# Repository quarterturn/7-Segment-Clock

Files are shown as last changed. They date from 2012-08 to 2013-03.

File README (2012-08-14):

A 7-segment clock based on the ATMEGA 328p, MAX7219 led driver, a DS1307 RTC and some old HP calculator common-cathode bubble lens displays.

Clock features:
- displays time: hh.mm.ss A.
  if 12-hour, shows A or P
  if alarm set, shows . in the A/P position
- displays date: mm.dd.yy D
  shows the day of week 1-7 at D
- when the date display is selected, the time scrolls over while still keeping time to reveal the date, pauses, and then scrolls back
- during set mode, the selected value blinks
- allows for start/stop schedule for DST, as well as disabling DST conversion
- DST conversion also works during time set; if in DST, the time is converted back to STD for the RTC
- RTC stores time in STD local time
- alarm function allows none, weekends, weekdays and all days schedule

Includes free Nyan Cat alarm tune. Tunes are made with the miditones utility and played via the Playtune library.

Note that though there are three timers on the ATMEGA 328p we use timer0 for millis() so we limit Playtune polyphony to two notes.

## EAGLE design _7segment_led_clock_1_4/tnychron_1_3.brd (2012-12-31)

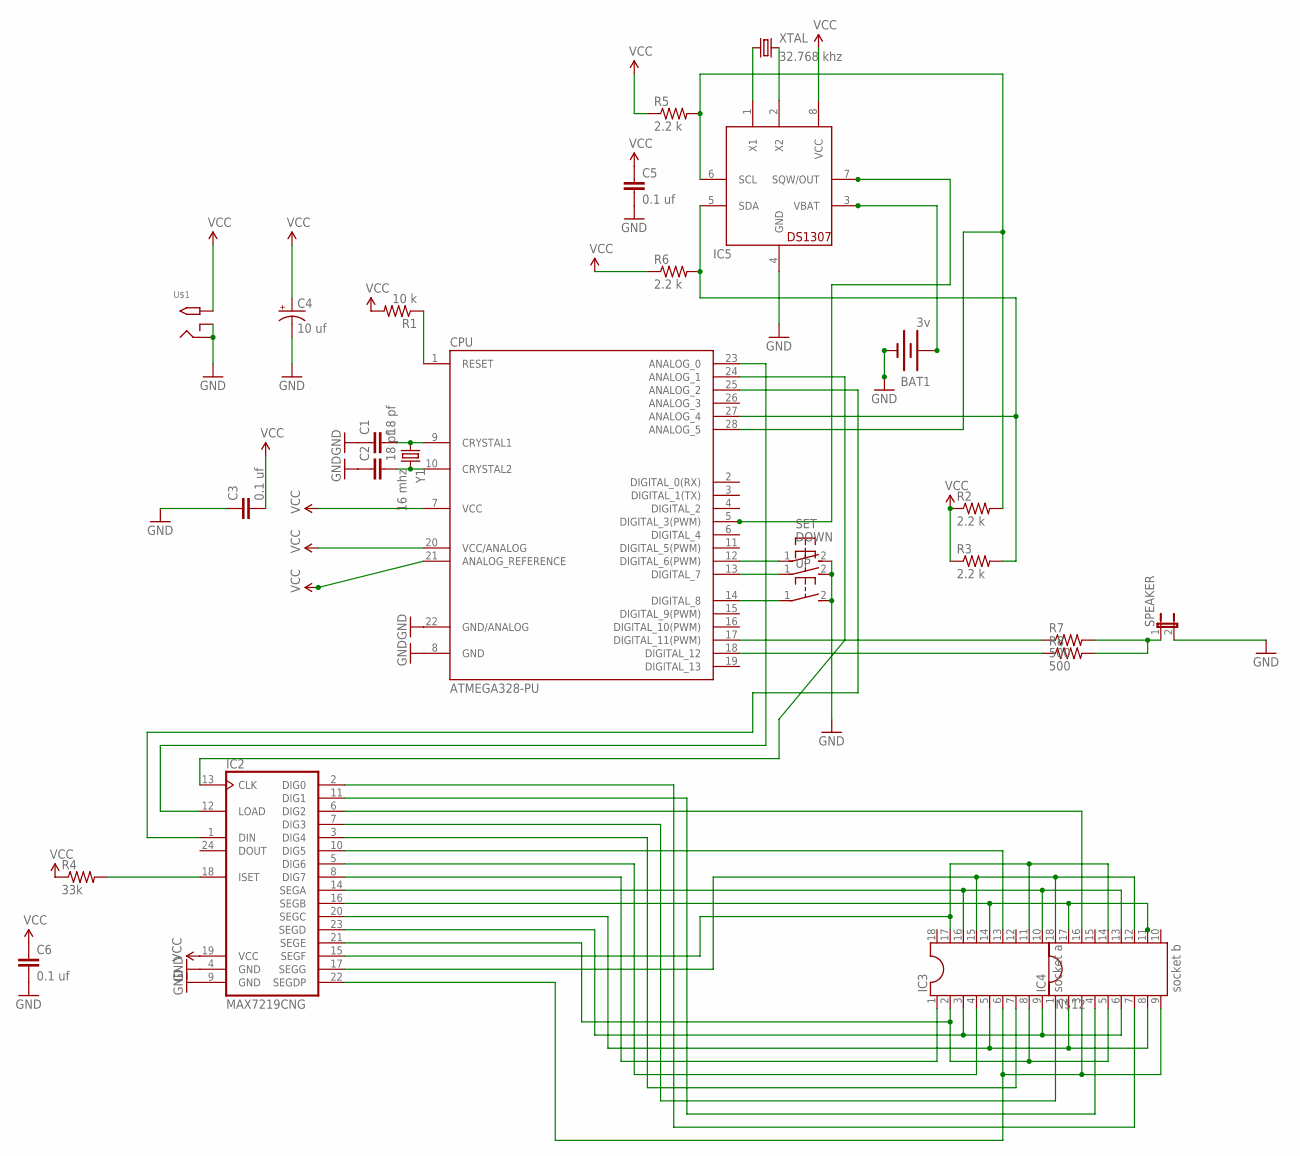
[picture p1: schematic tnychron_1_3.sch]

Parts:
BAT1: 3v; BATTCON_12MM_PTH
C1, C2: 18 pf; CAP-PTH-SMALL2
C3, C5, C6: 0.1 uf; CAP-PTH-SMALL2
C4: 10 uf; CPOL-RADIAL-10UF-25V
CPU: ATMEGA328-PU; DIL28-3
DOWN: 31-XX; B3F-31XX
IC2: MAX7219CNG; DIL24-3
IC3: socket a; DIL18
IC4: socket b; DIL18
IC5: DS1307; DIL08
R1: 10 k; AXIAL-0.4
R2, R3, R5, R6: 2.2 k; AXIAL-0.4
R4: 33k; AXIAL-0.4
R7, R8: 500; AXIAL-0.3
SET: 31-XX; B3F-31XX
SPEAKER: JUMPER-2PTH; 1X02
U$1: 2.1MMJACKTHM; PJ-102A
UP: 31-XX; B3F-31XX
XTAL: 32.768 khz; TC26H
Y1: 16 mhz; HC49US

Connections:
GND: BAT1.GND (-), C1.1, C2.1, C3.1, C4.2 (-), C5.2, C6.2, CPU.8 (GND), CPU.22 (GND/ANALOG), DOWN.2 (S), IC2.4 (GND), IC2.9 (GND), IC5.4 (GND), SET.2 (S), SPEAKER.2, U$1.RING, U$1.RING_SW, UP.2 (S)
unnamed: CPU.18 (DIGITAL_12), R8.P$1 (1)
unnamed: CPU.1 (RESET), R1.P$1 (1)
unnamed: C1.2, CPU.9 (CRYSTAL1), Y1.1
unnamed: C2.2, CPU.10 (CRYSTAL2), Y1.2
unnamed: IC2.2 (DIG0), IC4.7
unnamed: IC2.11 (DIG1), IC4.4
unnamed: CPU.28 (ANALOG_5), IC5.6 (SCL), R2.P$2 (2), R5.P$2 (2)
unnamed: CPU.27 (ANALOG_4), IC5.5 (SDA), R3.P$2 (2), R6.P$2 (2)
unnamed: CPU.5 (DIGITAL_3(PWM)), IC5.7 (SQW/OUT)
unnamed: CPU.17 (DIGITAL_11(PWM)), R7.P$1 (1)
unnamed: IC2.6 (DIG2), IC4.16
unnamed: IC2.7 (DIG3), IC4.1
unnamed: IC2.18 (ISET), R4.P$2 (2)
unnamed: IC2.3 (DIG4), IC3.7
unnamed: CPU.23 (ANALOG_0), IC2.12 (LOAD)
unnamed: CPU.24 (ANALOG_1), IC2.13 (CLK)
unnamed: CPU.25 (ANALOG_2), IC2.1 (DIN)
unnamed: IC2.10 (DIG5), IC3.13
unnamed: IC5.1 (X1), XTAL.1
unnamed: IC2.5 (DIG6), IC3.4
unnamed: IC2.8 (DIG7), IC3.1
unnamed: BAT1.VCC@1 (+), IC5.3 (VBAT)
unnamed: IC2.14 (SEGA), IC3.10, IC3.16, IC4.13
unnamed: IC2.16 (SEGB), IC3.14, IC4.11, IC4.17
unnamed: IC2.20 (SEGC), IC3.5, IC4.2, IC4.8
unnamed: IC2.23 (SEGD), IC3.3, IC3.9, IC4.6
unnamed: IC2.21 (SEGE), IC3.2, IC3.8, IC4.5
unnamed: CPU.12 (DIGITAL_6(PWM)), SET.1
unnamed: CPU.13 (DIGITAL_7), DOWN.1
unnamed: IC2.15 (SEGF), IC3.11, IC3.17, IC4.14
unnamed: IC2.17 (SEGG), IC3.15, IC4.12, IC4.18
unnamed: IC2.22 (SEGDP), IC3.6, IC4.3, IC4.9
unnamed: CPU.14 (DIGITAL_8), UP.1
unnamed: R7.P$2 (2), R8.P$2 (2), SPEAKER.1
unnamed: IC5.2 (X2), XTAL.2
VCC: C3.2, C4.1 (+), C5.1, C6.1, CPU.7 (VCC), CPU.20 (VCC/ANALOG), CPU.21 (ANALOG_REFERENCE), IC2.19 (VCC), IC5.8 (VCC), R1.P$2 (2), R2.P$1 (1), R3.P$1 (1), R4.P$1 (1), R5.P$1 (1), R6.P$1 (1), U$1.TIP

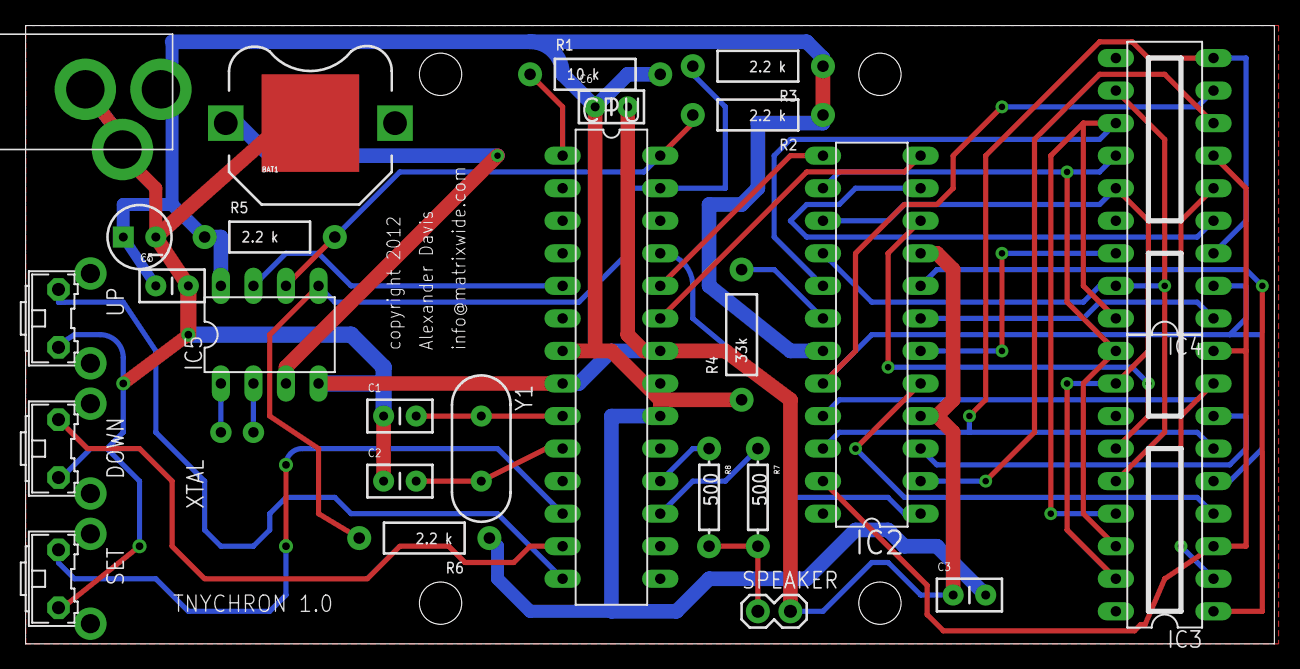
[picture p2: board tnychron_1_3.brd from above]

Board: 2 copper layers, 97.5 x 48.2 mm, 31 parts (1 on the bottom side), 37 nets.

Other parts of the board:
U$4, U$5, U$6, U$7: STAND-OFF

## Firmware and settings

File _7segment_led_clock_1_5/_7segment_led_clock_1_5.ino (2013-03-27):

/* teeny led clock
 
 Keeps time using a DS1307 RTC chip.
 
 The clock is controlled via a three button interface.
 
 The display is 3 HP 5082-7433 LED bubble displays driven by a MAX7219
 
 Version: 1.5
 Author: Alexander Davis
 Hardwarwe: ATMEGA328
 
 Uses the TimeLord library http://www.swfltek.com/arduino/timelord.html for DST calculation.
 
 Digital pins used:
 3 INT/SQW from DS1307 (active-low, set internal pull-up)
 10, 11, 12 for the MAX7219
 6, 7, 8 for buttons (active-low; set internal pull-ups to avoid external pull-down)
 
 Analog pins used:
 5, 4 i2c for DS1307
 */
 
 // Compatible with Ardunio 1.0

// for reading flash memory
#include <avr/pgmspace.h>
// for using atmega eeprom
#include <EEPROM.h>
// debounced button library
#include <Bounce.h>
// for 7 segment MAX7219 control
#include "LedControl.h"
// for using i2c interface
#include <Wire.h>
// for playing music
#include <Playtune.h>

// for time calculations
#include <TimeLord.h>

// global constants
#define SQW_PIN 3
#define SERIAL_BAUD 9600

// menus
#define M_INTRO 0
#define M_SET_TIME 1
#define M_SET_DATE 2
#define M_SET_AL 3
#define M_SET_24_HR 4
#define M_SET_DST 5
#define M_SET_DEFAULTS 6
#define M_SET_DONE 7
#define NUM_MENUS 7

#define SET_DEFAULTS 3
// to help remember time setting positions
#define HOURS_SET 0
#define MINUTES_SET 1
#define SECONDS_SET 2
#define PM_SET 3
// to help remember date setting positions
#define MONTHS_SET 0
#define DAYS_SET 1
#define YEARS_SET 2
#define DOW_SET 3
// to help remember alarm setting positions
#define AL_HOURS_SET 0
#define AL_MINUTES_SET 1
#define AL_DAY_SET 2
// to help remember for dst settings
#define DST_START_MON 0
#define DST_START_WEEK 1
#define DST_END_MON 2
#define DST_END_WEEK 3
#define DST_ENABLE 4
// to help remember the 12/24 hour settings
#define MODE_12_24_HOUR 0
// EEPROM memory locations for stored value
#define EE_DST_MON_START 0
#define EE_DST_WEEK_START 1
#define EE_DST_MON_END 2
#define EE_DST_WEEK_END 3
#define EE_TIME_MODE 4
#define EE_DST_ENABLE 5
#define EE_AL_HR 9
#define EE_AL_MIN 10
#define EE_AL_MODE 11

// how long to display the date
// 5 seconds
#define DATE_DELAY 5000

// how long to wait between scroll steps
// 250 mS
#define SCROLL_DELAY 200

// left side window rightmost scroll limit in display buffer
#define RIGHT_LIMIT 10
// left side window leftmost scroll limit in display buffer
#define LEFT_LIMIT 0

//i2c address of ds3231
#define DS1307_I2C_ADDRESS 0x68

// button setup - bounce objects
// 10 msec debounce interval
Bounce setButton = Bounce(6, 25);
Bounce decButton = Bounce(7, 25);
Bounce incButton = Bounce(8, 25);

// daylight savings time start and stop
byte dstMonStart;
byte dstDowStart = 1;
byte dstWeekStart;
byte dstMonEnd;
byte dstDowEnd = 1;
byte dstWeekEnd;
byte dstChangeHr = 2;
byte dstEnable = 1;
// 12 hour mode flag
byte is12Hour;

// day of week
byte day;
  
// array offsets
// 0 second
// 1 minute
// 2 hour
// 3 day
// 4 month
// 5 year

// dst time
byte theTime[6];

// alarm hour
byte alarmHr;
// alarm minute
byte alarmMin;
// alarm mode
// 0 - off
// 2 - weekends
// 5 - weekdays
// 7 - every day
byte alarmMode;

// flag if alarm should play
byte alarmPlay = 0;

// create a TimeLord object
TimeLord myLord;

/*
 LedControl pins
 pin 12 is connected to the DataIn 
 pin 11 is connected to the CLK 
 pin 10 is connected to LOAD 
 We have only a single MAX72XX.
 */
LedControl lc=LedControl(16,15,14,1);

// flag if time is ready per pin 3 interrupt
volatile byte displayNow = 0;

// track if date should be shown
byte showDate = 0;

// 16 character display buffer
char displayBuffer[18];

// there are 8 digits to the LED display
// therefore we use an 8 character window from the display buffer
// to display data
// left side of display window
byte dwL = 0;
// right side of display window
byte dwR = 7;

// delay for holding on the date display
int dateDelay = DATE_DELAY;

// for tracking time in delay loops
unsigned long previousMillis;

// string to be stored in flash at compile time
prog_char menu0[] PROGMEM = "TNYCHRON";
prog_char menu1[] PROGMEM = "SET TIME";
prog_char menu2[] PROGMEM = "SET DATE";
prog_char menu3[] PROGMEM = "SET AL  ";
prog_char menu4[] PROGMEM = "SET 24HR";
prog_char menu5[] PROGMEM = "SET DST ";
prog_char menu6[] PROGMEM = "SET DFLT";
prog_char menu7[] PROGMEM = "DONE    ";

// Playtune bytestream for file "nyancat1.mid" created by MIDITONES V1.4 on Sat Aug 11 09:57:09 2012
byte PROGMEM score [] = {
0x90,0x4E, 0x91,0x28, // 
0,214, 0x80, 0x81, 0x90,0x50, 0x91,0x34, 0,214, 0x80, 0x81, 0x90,0x4B, 0x91,0x2A, 0,107, 
0x80, 0x90,0x4B, 0,107, 0x81, 0x91,0x36, 0,107, 0x80, 0x90,0x47, 0,107, 0x81, 0x80, 0x91,0x27, 0x90,0x4A, 
0,107, 0x80, 0x90,0x49, 0,107, 0x81, 0x80, 0x91,0x33, 0x90,0x47, 0,214, 0x81, 0x80, 0x91,0x2C, 0x90,0x47, 
0,214, 0x81, 0x80, 0x91,0x38, 0x90,0x49, 0,214, 0x81, 0x80, 0x91,0x25, 0x90,0x4A, 0,214, 0x81, 0x80, 0x91,0x31, 
0x90,0x4A, 0,107, 0x80, 0x90,0x49, 0,107, 0x81, 0x80, 0x91,0x2A, 0x90,0x47, 0,107, 0x80, 0x90,0x49, 0,107, 
0x81, 0x80, 0x91,0x36, 0x90,0x4B, 0,107, 0x80, 0x90,0x4E, 0,107, 0x81, 0x80, 0x91,0x23, 0x90,0x50, 0,107, 
0x80, 0x90,0x4B, 0,107, 0x81, 0x80, 0x91,0x2F, 0x90,0x4E, 0,107, 0x80, 0x90,0x49, 0,107, 0x81, 0x80, 0x91,0x23, 
0x90,0x4B, 0,107, 0x80, 0x90,0x47, 0,107, 0x81, 0x80, 0x91,0x2F, 0x90,0x49, 0,107, 0x80, 0x90,0x47, 0,107, 
0x81, 0x80, 0x91,0x28, 0x90,0x4B, 0,214, 0x81, 0x80, 0x91,0x34, 0x90,0x4E, 0,214, 0x81, 0x80, 0x91,0x2A, 0x90,0x50, 
0,107, 0x80, 0x90,0x4B, 0,107, 0x81, 0x80, 0x91,0x36, 0x90,0x4E, 0,107, 0x80, 0x90,0x49, 0,107, 0x81, 
0x80, 0x91,0x27, 0x90,0x4B, 0,107, 0x80, 0x90,0x47, 0,107, 0x81, 0x80, 0x91,0x33, 0x90,0x49, 0,107, 0x80, 
0x90,0x4B, 0,107, 0x81, 0x80, 0x91,0x2C, 0x90,0x4A, 0,107, 0x80, 0x90,0x49, 0,107, 0x81, 0x80, 0x91,0x38, 
0x90,0x47, 0,107, 0x80, 0x90,0x49, 0,107, 0x81, 0x80, 0x91,0x25, 0x90,0x4A, 0,214, 0x81, 0x80, 0x91,0x31, 
0x90,0x47, 0,107, 0x80, 0x90,0x49, 0,107, 0x81, 0x80, 0x91,0x2A, 0x90,0x4A, 0,107, 0x80, 0x90,0x4E, 0,107, 
0x81, 0x80, 0x91,0x36, 0x90,0x49, 0,107, 0x80, 0x90,0x4B, 0,107, 0x81, 0x80, 0x91,0x23, 0x90,0x49, 0,107, 
0x80, 0x90,0x47, 0,107, 0x81, 0x80, 0x91,0x2F, 0x90,0x49, 0,214, 0x81, 0x80, 0x91,0x23, 0x90,0x47, 0,214, 
0x81, 0x80, 0x91,0x2F, 0x90,0x49, 0,214, 0x81, 0x80, 0x91,0x28, 0x90,0x4E, 0,214, 0x81, 0x80, 0x91,0x34, 0x90,0x50, 
0,214, 0x81, 0x80, 0x91,0x2A, 0x90,0x4B, 0,107, 0x80, 0x90,0x4B, 0,107, 0x81, 0x91,0x36, 0,107, 0x80, 
0x90,0x47, 0,107, 0x81, 0x80, 0x91,0x27, 0x90,0x4A, 0,107, 0x80, 0x90,0x49, 0,107, 0x81, 0x80, 0x91,0x33, 
0x90,0x47, 0,214, 0x81, 0x80, 0x91,0x2C, 0x90,0x47, 0,214, 0x81, 0x80, 0x91,0x38, 0x90,0x49, 0,214, 0x81, 
0x80, 0x91,0x25, 0x90,0x4A, 0,214, 0x81, 0x80, 0x91,0x31, 0x90,0x4A, 0,107, 0x80, 0x90,0x49, 0,107, 0x81, 
0x80, 0x91,0x2A, 0x90,0x47, 0,107, 0x80, 0x90,0x49, 0,107, 0x81, 0x80, 0x91,0x36, 0x90,0x4B, 0,107, 0x80, 
0x90,0x4E, 0,107, 0x81, 0x80, 0x91,0x23, 0x90,0x50, 0,107, 0x80, 0x90,0x4B, 0,107, 0x81, 0x80, 0x91,0x2F, 
0x90,0x4E, 0,107, 0x80, 0x90,0x49, 0,107, 0x81, 0x80, 0x91,0x23, 0x90,0x4B, 0,107, 0x80, 0x90,0x47, 0,107, 
0x81, 0x80, 0x91,0x2F, 0x90,0x49, 0,107, 0x80, 0x90,0x47, 0,107, 0x81, 0x80, 0x91,0x28, 0x90,0x4B, 0,214, 
0x81, 0x80, 0x91,0x34, 0x90,0x4E, 0,214, 0x81, 0x80, 0x91,0x2A, 0x90,0x50, 0,107, 0x80, 0x90,0x4B, 0,107, 
0x81, 0x80, 0x91,0x36, 0x90,0x4E, 0,107, 0x80, 0x90,0x49, 0,107, 0x81, 0x80, 0x91,0x27, 0x90,0x4B, 0,107, 
0x80, 0x90,0x47, 0,107, 0x81, 0x80, 0x91,0x33, 0x90,0x49, 0,107, 0x80, 0x90,0x4B, 0,107, 0x81, 0x80, 0x91,0x2C, 
0x90,0x4A, 0,107, 0x80, 0x90,0x49, 0,107, 0x81, 0x80, 0x91,0x38, 0x90,0x47, 0,107, 0x80, 0x90,0x49, 0,107, 
0x81, 0x80, 0x91,0x25, 0x90,0x4A, 0,214, 0x81, 0x80, 0x91,0x31, 0x90,0x47, 0,107, 0x80, 0x90,0x49, 0,107, 
0x81, 0x80, 0x91,0x2A, 0x90,0x4A, 0,107, 0x80, 0x90,0x4E, 0,107, 0x81, 0x80, 0x91,0x36, 0x90,0x49, 0,107, 
0x80, 0x90,0x4B, 0,107, 0x81, 0x80, 0x91,0x23, 0x90,0x49, 0,107, 0x80, 0x90,0x47, 0,107, 0x81, 0x80, 0x91,0x2F, 
0x90,0x49, 0,214, 0x81, 0x80, 0x91,0x23, 0x90,0x47, 0,214, 0x81, 0x80, 0x91,0x2F, 0x90,0x47, 0,214, 0x81, 
0x80, 0x91,0x34, 0x90,0x47, 0,214, 0x81, 0x80, 0x91,0x38, 0x90,0x42, 0,107, 0x80, 0x90,0x44, 0,107, 0x81, 
0x80, 0x91,0x3B, 0x90,0x47, 0,214, 0x81, 0x80, 0x91,0x40, 0x90,0x42, 0,107, 0x80, 0x90,0x44, 0,107, 0x81, 
0x80, 0x91,0x33, 0x90,0x47, 0,107, 0x80, 0x90,0x49, 0,107, 0x81, 0x80, 0x91,0x36, 0x90,0x4B, 0,107, 0x80, 
0x90,0x47, 0,107, 0x80, 0x90,0x4C, 0,107, 0x80, 0x90,0x4B, 0,107, 0x81, 0x80, 0x91,0x3F, 0x90,0x4C, 0,107, 
0x80, 0x90,0x4E, 0,107, 0x81, 0x80, 0x91,0x31, 0x90,0x47, 0,214, 0x81, 0x80, 0x91,0x34, 0x90,0x47, 0,214, 
0x81, 0x80, 0x91,0x38, 0x90,0x42, 0,107, 0x80, 0x90,0x44, 0,107, 0x81, 0x80, 0x91,0x3D, 0x90,0x47, 0,107, 
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
// This score contains 2704 bytes, and 2 tone generators are used.
// 64 notes had to be skipped.


// array of menu strings stored in flash
PROGMEM const char *menuStrSet[] = {
  menu0,
  menu1,
  menu2,
  menu3,
  menu4,
  menu5,
  menu6,
  menu7
};

// instantate a Playtune object
Playtune pt;

// setup
void setup(void)
{
  // set up the serial port
  Serial.begin(SERIAL_BAUD);
  
  // button setup
  // enable internal pull-ups
  pinMode(6, INPUT);
  digitalWrite(6, HIGH);
  pinMode(7, INPUT);
  digitalWrite(7, HIGH);
  pinMode(8, INPUT);
  digitalWrite(8, HIGH);
  
  // pin 3 set interrupt on SQW
  pinMode(3, INPUT);
  digitalWrite(3, HIGH);
  attachInterrupt(1, SQWintHandler, FALLING);
  
  // set playtune pins on the two available PWM timers
  // had problems with pin 10 - maybe millis() timer0 or something else
  //pt.tune_initchan (10); 
  pt.tune_initchan (11);
  pt.tune_initchan (12);
  
  // turn on the max7219
  lc.shutdown(0,false);
  // set the brightness to 12
  lc.setIntensity(0,12);
  // clear the display
  lc.clearDisplay(0);

  // timezone and dst info
  dstMonStart = EEPROM.read(EE_DST_MON_START);
  dstWeekStart = EEPROM.read(EE_DST_WEEK_START);
  dstMonEnd = EEPROM.read(EE_DST_MON_END);
  dstWeekEnd = EEPROM.read(EE_DST_WEEK_END);
  dstEnable = EEPROM.read(EE_DST_ENABLE);
  is12Hour = EEPROM.read(EE_TIME_MODE);
 
  alarmHr = EEPROM.read(EE_AL_HR);
  alarmMin = EEPROM.read(EE_AL_MIN);
  alarmMode = EEPROM.read(EE_AL_MODE);
  
  // display version and contact info
  intro();
  lc.clearDisplay(0);

  // clear /EOSC bit
  // Sometimes necessary to ensure that the clock
  // keeps running on just battery power. Once set,
  // it shouldn't need to be reset but it's a good
  // idea to make sure.
  Wire.begin();
  Wire.beginTransmission(DS1307_I2C_ADDRESS); // address DS3231
  Wire.write(0x0E); // select register
  Wire.write(0b00011100); // write register bitmap, bit 7 is /EOSC
  Wire.endTransmission();

  // enable the SQW pin output
  // the function sets it to 1 HZ
  SQWEnable();
  
  // set dst rules
  myLord.DstRules(dstMonStart, dstWeekStart, dstMonEnd, dstWeekEnd, 60);
  
  // grab the date and time for use in sun calculations
  getTimeRtc();
  
  // convert time to dst if enabled
  if (dstEnable)
  {
    myLord.DST(theTime);
  }
  
  // compute the day of week
  day = myLord.DayOfWeek(theTime);
}

//---------------------------------------------------------------------------------------------//
// main loop
//---------------------------------------------------------------------------------------------//
void loop(void)
{
  // get the time and date
  // if pin 3 interrupt has triggered
  if (displayNow)
  {
    ////Serial.println("SQW interrupt");
    getTimeRtc();
    
    // convert time to dst if enabled
    if (dstEnable)
    {
      myLord.DST(theTime);
    }
    
    // compute the day of week
    day = myLord.DayOfWeek(theTime);
    
    // reset displayNow
    displayNow = 0;
    // load the new time and date into the display buffer
    updateBuffer();
  }
  
  // check if the alarm should go off
  if (alarmMode > 0)
  {
    // check if the minute just began
    if (theTime[0] == 0)
    {
      // check if the alarm time matches
      if ((theTime[1] == alarmMin) && (theTime[2] == alarmHr))
      {
        // alarm every day
        if (alarmMode == 7)
        {
          // start the alarm tune
          pt.tune_playscore (score);
          // flag that the alarm is playing
          alarmPlay = 1;
        }
        // alarm on the weekend
        else if ((alarmMode == 2) && ((day == 1) || (day == 7)))
        {
          pt.tune_playscore (score);
          alarmPlay = 1;
        }
        // alarm during the week
        else if ((alarmMode == 5) && ((day == 2) || (day == 3) || (day == 4) || (day == 5) || (day == 6)))
        {
          pt.tune_playscore (score);
          alarmPlay = 1;
        }
      }
    }
  }
  
  // update the display from the buffer based on the display window
  updateDisplay(dwL, dwR);
  
  // grab now
  previousMillis = millis();
  // poll the buttons while waiting to update the display
  // after every SCROLL_DELYAY ms the display is updated
  // this provides a timing loop governing the display scroll speed
  // during a scroll from time to date and back
  while (millis() - previousMillis < SCROLL_DELAY)
  { 
    
    // get the time and date
    // if pin 3 interrupt has triggered
    if (displayNow)
    {
      getTimeRtc();
      // convert time to dst if enabled
      if (dstEnable)
      {
        myLord.DST(theTime);
      } 
      // compute the day of week
      day = myLord.DayOfWeek(theTime);
      // reset displayNow
      displayNow = 0;
      // load the new time and date into the display buffer
      updateBuffer();
    }
    
    // set button is pressed
    if (setButton.update())
    {
      if (setButton.read() == LOW)
      {
        // enter set mode
        setMenu();
      }
    }
    
    // start the alarm playing or restart it if finished
    if (alarmPlay == 1)
    {
      // if not playing, start playing
      if (pt.tune_playing == 0)
      {
        pt.tune_playscore (score);
      }
      // otherwise the tune must be playing so leave it alone
    }
    
    // if incButton was pressed
    // set the flag to start moving the display window rightward
    // on each exit from the timing loop
    // also used as the button to stop the alarm
    if (incButton.update())
    {
      if (incButton.read() == LOW)
      {
        if (alarmPlay == 1)
        {
          alarmPlay = 0;
          // stop the music
          pt.tune_stopscore();
        }
        
        if (showDate == 0)
        {
          showDate = 1;
        }
      }
    }
  }
  // end of timing loop
  
  // increment the display window if showDate is 1
  if (showDate == 1)
  {
    // if we have not reached the final rightmost position for the date
    // keep incrementing the window position
    if (dwL < RIGHT_LIMIT)
    {
      //Serial.print("incrementing ");
      //Serial.println(dwL, DEC);
      dwL++;
      dwR++;
    }
    // if we have scrolled the display window all the way to the right
    // decrement the dateDelay on every pass through the timing loop
    // this will pause the display on the date
    if ((dwL == RIGHT_LIMIT) && (dateDelay > 0))
    {
      //Serial.print("holding ");
      //Serial.println(dwL, DEC);
      dateDelay = dateDelay - 250;
    }
    
    // once the delay is used up scroll back
    if ((dwL == RIGHT_LIMIT) && (dateDelay == 0))
    {
      //Serial.print("hold time expired ");
      //Serial.println(dwL, DEC);
      showDate = 2;
    }
  }
  // decrement the display window if showDate is 2
  if (showDate == 2)
  {
    // if we have not reach the final leftmost position for the time
    // keep decrementing the window position
    if (dwL > LEFT_LIMIT)
    {
      //Serial.print("decrementing ");
      //Serial.println(dwL, DEC);
      dwL--;
      dwR--;
    }
    // if we reach the leftmost window limit for the time stop scrolling
    // and set showDate back to 0
    if (dwL == LEFT_LIMIT)
    {
      //Serial.print("back to regular ");
      //Serial.println(dwL, DEC);
      showDate = 0;
      dateDelay = DATE_DELAY;
    }
  }   
}

//---------------------------------------------------------------------------------------------//
// function SQWintHandler
// sets displayNow on SQW pin 3 interrupt
// we keep it quick to minimize impact on other processes
//---------------------------------------------------------------------------------------------//
void SQWintHandler(void)
{
  displayNow = 1;
}

//---------------------------------------------------------------------------------------------//
// function setMenu
// displays the choices for setting the clock
//---------------------------------------------------------------------------------------------//
void setMenu(void)
{
  // default menu item is "set time"
  byte menuNum = 1;

  // default to time and date menu
  // strcpy_P(currentString, (char*)pgm_read_word(&(menuStrSet[menuNum])));
  strcpy_P(displayBuffer, (char*)pgm_read_word(&(menuStrSet[menuNum])));

  // print the menu to the LED display
  updateDisplay(0, 7);


  // loop until exit
  while (1)
  {
    // down button goes to previous menu unless already there
    if (decButton.update() && (menuNum > 1))
    {
      if (decButton.read() == LOW)
      {
        menuNum--;
        strcpy_P(displayBuffer, (char*)pgm_read_word(&(menuStrSet[menuNum])));
        updateDisplay(0, 7);
        //Serial.print("decButton");
        //Serial.println(menuNum, DEC);
      }
    }
    // up button goes to next menu unless already at last one
    if (incButton.update() && (menuNum < NUM_MENUS))
    {
      if (incButton.read() == LOW)
      {
        menuNum++;
        strcpy_P(displayBuffer, (char*)pgm_read_word(&(menuStrSet[menuNum])));
        updateDisplay(0, 7);
        //Serial.print("incButton");
        //Serial.println(menuNum, DEC);
      }
    }
    // center button selects the current menu choice
    if (setButton.update())
    {
      if (setButton.read() == LOW)
      {
        //Serial.print("setButton");
        //Serial.println(menuNum, DEC);
        switch(menuNum)
        {
          case M_SET_TIME:
            setTime();
            return;
            break;
          case M_SET_DATE:
            setDate();
            return;
            break;
          case M_SET_AL:
            setAlarm();
            return;
            break;
          case M_SET_24_HR:
            set1224Mode();
            return;
            break;     
          case M_SET_DST:
            setDstStartEnd();
            return;
            break;
          case M_SET_DONE:
            return;
            break;
          case M_SET_DEFAULTS:
            setDefaults();
            return;
            break;
          default:
            return;
            break;
        }
      }
    } 
  }
  return;
}
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

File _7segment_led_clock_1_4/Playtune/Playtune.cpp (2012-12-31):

/******************************************************************************
*
* Playtune: An Arduino Tune Generator library
*
* Plays a polyphonic musical score.
*
*   (C) Copyright 2011, Len Shustek
*
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
*   This was inspired by and adapted from "A Tone Generator Library",
*   written by Brett Hagman, http://www.roguerobotics.com/
*
**************************************************************************/
/*
* Change log
*  19 January 2011, L.Shustek, V1.0
*     - Initial release.
*  23 February 2011, L. Shustek, V1.1
*	- prevent hang if delay rounds to count of 0
*
*/

/*---------------------------------------------------------------------------------
*
*
*                              About Playtune
*
*
*  Playtune interprets a bytestream of commands that represent a polyphonic musical
*  score.  It uses the Arduino counters for generating tones, so the number of
*  simultaneous notes that can be played depends on which processor you have.
*  The NANO allows 3, and the MEGA 2560 allows 6.  Each timer (tone generator) can
*  be associated with any digital output pin, not just the pins that are internally
*  connected to the timer.
*
*  Once a score starts playing, all of the processing happens in interrupt routines,
*  so any other "real" program can be running at the same time, as long as it doesn't
*  use the timers or output pins that Playtune is using.  Playtune generates a lot of
*  interrupts because the toggling of the output bits is done in software, not by the
*  timer hardware.  But measurements I've made on a NANO show that Playtune uses less
*  than 10% of the available processor cycles even when playing all three channels at
*  pretty high frequencies.
*
*  The easiest way to hear the music is to connect each of the output pins to a resistor
*  (500 ohms, say).  Connect other ends of the resistors together and then to one
*  terminal of an 8-ohm speaker.  The other terminal of the speaker is connected to
*  ground.  No other hardware is needed!  If you are going to connect to an amplifier,
*  you should DC-isolate the signal using a capacitor.
*
*  There is no volume modulation.  All tones are played at the same volume, which
*  makes some scores sound strange.  This is definitely not a high-quality synthesizer.
*
*
*  *****  The public Playtune interface  *****
*
*  There are five public functions and one public variable.
*
*  void tune_initchan(byte pin)
*
*    Call this to initialize each of the tone generators you want to use.  The argument
*    says which pin to use as output.  The pin numbers are the digital "D" pins
*    silkscreened on the Arduino board.  Calling this more times than your processor
*    has timers will do no harm, but will not help either.
*
*  void tune_playscore (byte *score)
*
*    Call this pointing to a "score bytestream" to start playing a tune.  It will
*    only play as many simultaneous notes as you have initialized tone generators;
*    any more will be ignored.  See below for the format of the score bytestream.
*
*  boolean tune_playing
*
*    This global variable will be "true" if a score is playing, and "false" if not.
*    You can use this to see when a score has finished.
*
*  void tune_stopscore()
*
*    This will stop a currently playing score without waiting for it to end by itself.
*
*  void tune_delay (unsigned int msec)
*
*    Delay for "msec" milliseconds.  This is provided because the usual Arduino
*    "delay" function will stop working if you use all of your processor's
*    timers for generating tones.
*
*  void tune_stopchans ()
*
*    This disconnects all the timers from their pins and stops the interrupts.
*    Do this when you don't want to play any more tunes.
*
*
*  *****  The score bytestream  *****
*
*  The bytestream is a series of commands that can turn notes on and off, and can
*  start a waiting period until the next note change.  Here are the details, with
*  numbers shown in hexadecimal.
*
*  If the high-order bit of the byte is 1, then it is one of the following commands:
*
*    9t nn  Start playing note nn on tone generator t.  Generators are numbered
*           starting with 0.  The notes numbers are the MIDI numbers for the chromatic
*           scale, with decimal 60 being Middle C, and decimal 69 being Middle A
*           at 440 Hz.  The highest note is decimal 127 at about 12,544 Hz.
*
*    8t     Stop playing the note on tone generator t.
*
*    F0     End of score: stop playing.
*
*    E0     End of score: start playing again from the beginning.
*
*  If the high-order bit of the byte is 0, it is a command to wait.  The other 7 bits
*  and the 8 bits of the following byte are interpreted as a 15-bit big-endian integer
*  that is the number of milliseconds to wait before processing the next command.
*  For example,
*
*    07 D0
*
*  would cause a wait of 0x07d0 = 2000 decimal millisconds or 2 seconds.  Any tones
*  that were playing before the wait command will continue to play.
*
*  The score is stored in Flash memory ("PROGMEM") along with the program, because
*  there's a lot more of that than data memory.
*
*
*  *****  Where does the score data come from?  *****
*
*  Well, you can write the score by hand from the instructions above, but that's
*  pretty hard.  An easier way is to translate MIDI files into these score commands,
*  and I've written a program called "miditones" to do that.  See the separate
*  documentation for that program, which is also open source.
*
*
*  *****  More gory details  *****
*
*  The number of hardware timers, and therefore the number of tones that can be
*  played simultaneously, depends on the processor that is on your board:
*
*    ATMega8: 2 tones  (timers 2 and 1)
*    ATmega168/328: 3 tones (timers 2, 1, and 0)
*    ATmega1280/2560: 6 tones (timers 2, 3, 4, 5, 1, and 0)
*
*  The order listed above is the order that timers are assigned as you make
*  succesive calls to play_initchan().  Timer 0 is assigned last, because using
*  it will disable the Arduino millis(), delay(), and the PWM functions.
*
*  The lowest MIDI note that can be played using the 8-bit timers (0 and 2)
*  depends on your processor's clock frequency.
*     8 Mhz clock: note 12 (about 16.5 Hz, which is below the piano keyboard)
*    16 Mhz clock: note 24 (about 32.5 Hz, C in octave 1)
*
*  The highest MIDI note (127, about 12,544 Hz) can always be played, but can't
*  always be heard.
*
*
*  *****  Nostalgia from me  *****
*
*  Writing Playtune was a lot of fun, because it essentially duplicates what I did
*  as a graduate student at Stanford University in about 1973.  That project used the
*  then-new Intel 8008 microprocessor, plus three hardware square-wave generators that
*  I built out of 7400-series TTL.  The music compiler was written in Pascal and read
*  scores that were hand-written in a notation I made up that looked something like
*      C  Eb  4G  8G+  2R  +  F  D#
*  This was done was before MIDI had been invented, and anyway I wasn't a pianist so I
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

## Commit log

2012-08-14 Tinychron 1.3 a complete LED digital clock
    based on:
    ATMEGA 328p micro
    DS1307 RTC
    MAX7219 LED display controller
    Uses these external libraries:
    Timelord
    Bounce
    LedContol
    Playtune
    Includes "Nyan Cat" looping alarm tune
    miditones utility can be used to compile in a new tune
    Features:
    Power-loss timekeeping thanks to DS1307 backup battery
    DST time correction schedule
    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
    [_7segment_led_clock_1_3.ino]
2012-12-31 software v 1.3 and Eagle CAD files
    [tnychron_1_3.brd, tnychron_1_3.sch]
2012-12-31 software v 1.3, Eagle CAD files and Ardunio libraries
2013-01-22 v 1.4 bugfix for alarm minutes stored as alarmHr
    [tnychron_1_3.brd, tnychron_1_3.sch]

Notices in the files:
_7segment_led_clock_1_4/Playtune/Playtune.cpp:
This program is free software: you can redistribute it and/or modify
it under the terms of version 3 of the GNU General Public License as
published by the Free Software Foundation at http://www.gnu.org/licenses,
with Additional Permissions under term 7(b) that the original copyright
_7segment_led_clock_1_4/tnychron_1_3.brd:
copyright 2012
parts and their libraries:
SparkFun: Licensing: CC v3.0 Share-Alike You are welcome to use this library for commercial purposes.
